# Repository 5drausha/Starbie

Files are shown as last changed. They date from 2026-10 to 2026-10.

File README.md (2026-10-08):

# Squarebie

This project is a modification of the Starbie starter project. Since I wanted to make something original, I decided to go down a slightly different path to Starbie. I wanted to turn this into more of a mini computer, desk assistant and macropad rather than a virtual pet.

Above is the picture of the 3d model (doesn't have the button caps in the model).

This is a picture of just the electronics.

This is the case.

And this is my PCB model.

My plan is to have this Squarbie be used as a sort of second mini device that pairs with my computer. I plan to have an app where you can do things such as set timers, reminders, make the 3 buttons on it customizable macropad keys, and display custom animations on it. But I'll have to leave that for later as I need the board in person (I don't know how to do it without it) to make the app. But for now, it functions as its own mini computer, with a stopwatch, a counter, and a reaction time game, which is still fully functional. Here is a picture of its simulated version:


This was a fun project and I learnt A LOT making this. I have never designed something in a CAD, so this was a great learning experience. Really looking forward to next week's project. :)

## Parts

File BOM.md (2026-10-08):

# Starbie – bill of materials

<!-- Generated by Half Life from project cmuuqodtk09mt01smeao56xzq. Edits here are overwritten on the next sync. -->
<!-- Generated: 2026-10-08T01:15:49.758Z -->

> [!NOTE]
> This parts list is mirrored from [Half Life](https://halflife.hackclub.com). Editing it here will not change the platform's copy, and the next sync overwrites this file.

| Week | Tier | Parts funding |
| --- | --- | --- |
| Week 1 | Tier 1 | $30.00 |

| Part | What it's for | Qty | Unit | Total | Vendor |
| --- | --- | --- | --- | --- | --- |
| [PCB board](https://cart.jlcpcb.com/quote?quoteTab=standardPcb) | Holds all the pieces and makes connections without wires. | 1 | $2.00 | $2.00 | [JLCPCB (JLCLONE)](https://cart.jlcpcb.com/quote?quoteTab=standardPcb) |
| [Seeed Studio XIAO ESP32 C3](https://www.aliexpress.com/item/1005007427033011.html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) | The main microcontroller of the whole project | 1 | $7.78 | $7.78 | [Aliexpress (SpotPear Electronics)](https://www.aliexpress.com/item/1005007427033011.html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) |
| [12mmx12mm tactile buttons](https://www.aliexpress.com/item/1005001629272642.html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) | The 3 buttons in the Squarebire I'm making (comes in packs of  10pcs) | 10 | $0.31 | $3.10 | [Aliexpress (HAPPYVIEW Electronics)](https://www.aliexpress.com/item/1005001629272642.html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) |
| [0.96 inch OLED I2C display](https://www.aliexpress.com/item/1005006901360788.html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) | The screen of the project, the output. | 1 | $2.69 | $2.69 | [Aliexpress (TENSTAR ROBOT Store)](https://www.aliexpress.com/item/1005006901360788.html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) |
| [Case top plate](https://jlc3dp.com/) | 3D printed case (top part) | 1 | $0.75 | $0.75 | [JLC3DP](https://jlc3dp.com/) |
| [Case Bottom Part](https://jlc3dp.com/) | What actually holds the components. The main Compartment | 1 | $1.59 | $1.59 | [JLC3DP](https://jlc3dp.com/) |
| **Parts subtotal** | — | — | — | **$17.91** | — |
| **Tax & shipping** | — | — | — | **$2.71** | — |
| **Total** | — | — | — | **$20.62** | — |

$9.38 left of the tier's funding.

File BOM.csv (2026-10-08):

Item | Quantity | Vendor | Unit Price (NZD) | Total Price (USD)
Display_128x64_096_I2C | 1 | Aliexpress | $4.79 | $2.69
12mmx12mm Tactile Switch | 10 | Aliexpress | $0.56 | $3.13
XIAO-ESP32 C6 DIP | 1 | Aliexpress | $13.90 | $7.78
PCB Board | 5 | JLCPCB | $0.71 | $2.00
Case (Bottom + Top) | 1 | JLC3DP | $4.18 | $2.34
Shipping + Tax | \ | \ | $4.84 | $2.71
Total | \ | \ | \ | $20.65

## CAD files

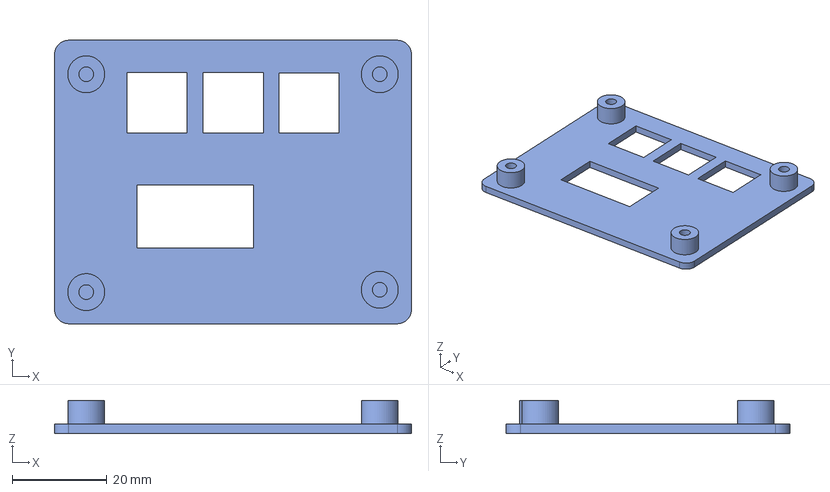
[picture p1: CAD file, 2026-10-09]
Top part of case (rounded).step
75.4 x 59.9 x 7.00 mm

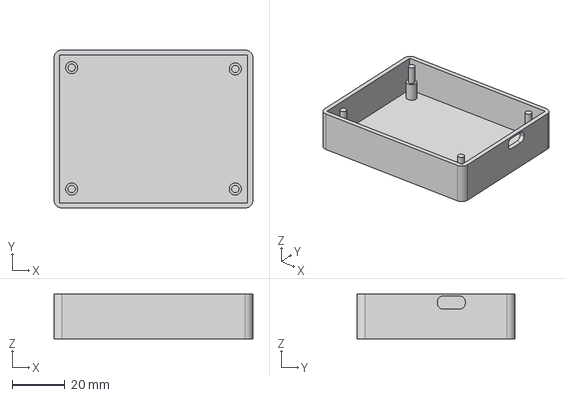
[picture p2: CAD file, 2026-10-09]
Bottom part of case (rounded).step
75.4 x 59.9 x 17.0 mm

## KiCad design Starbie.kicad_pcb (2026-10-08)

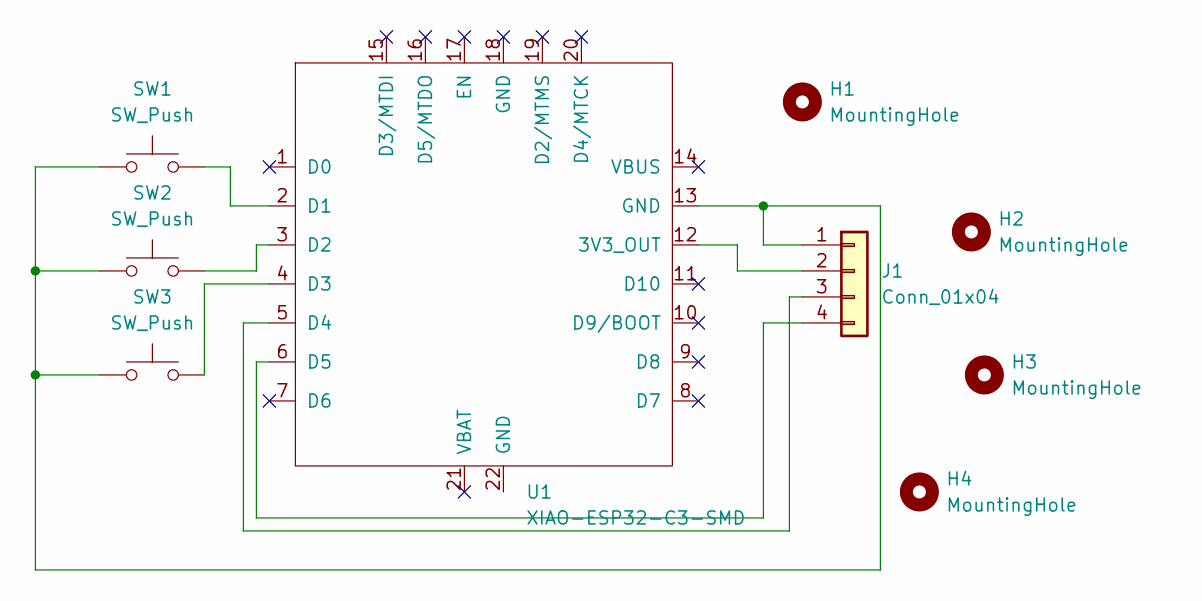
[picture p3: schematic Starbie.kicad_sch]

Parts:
H1, H2, H3, H4: MountingHole; MountingHole_3.2mm_M3
J1: Conn_01x04; Display_128x64_096_I2C
SW1, SW2, SW3: SW_Push; SW_PUSH-12mm
U1: XIAO-ESP32-C3-SMD; XIAO-ESP32-C6-DIP

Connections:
unnamed: J1.1, SW1.1, SW2.1, SW3.1, U1.13 (GND)
unnamed: J1.2, U1.12 (3V3_OUT)
unnamed: J1.3, U1.5 (D4)
unnamed: J1.4, U1.6 (D5)
unnamed: SW1.2, U1.2 (D1)
unnamed: SW2.2, U1.3 (D2)
unnamed: SW3.2, U1.4 (D3)

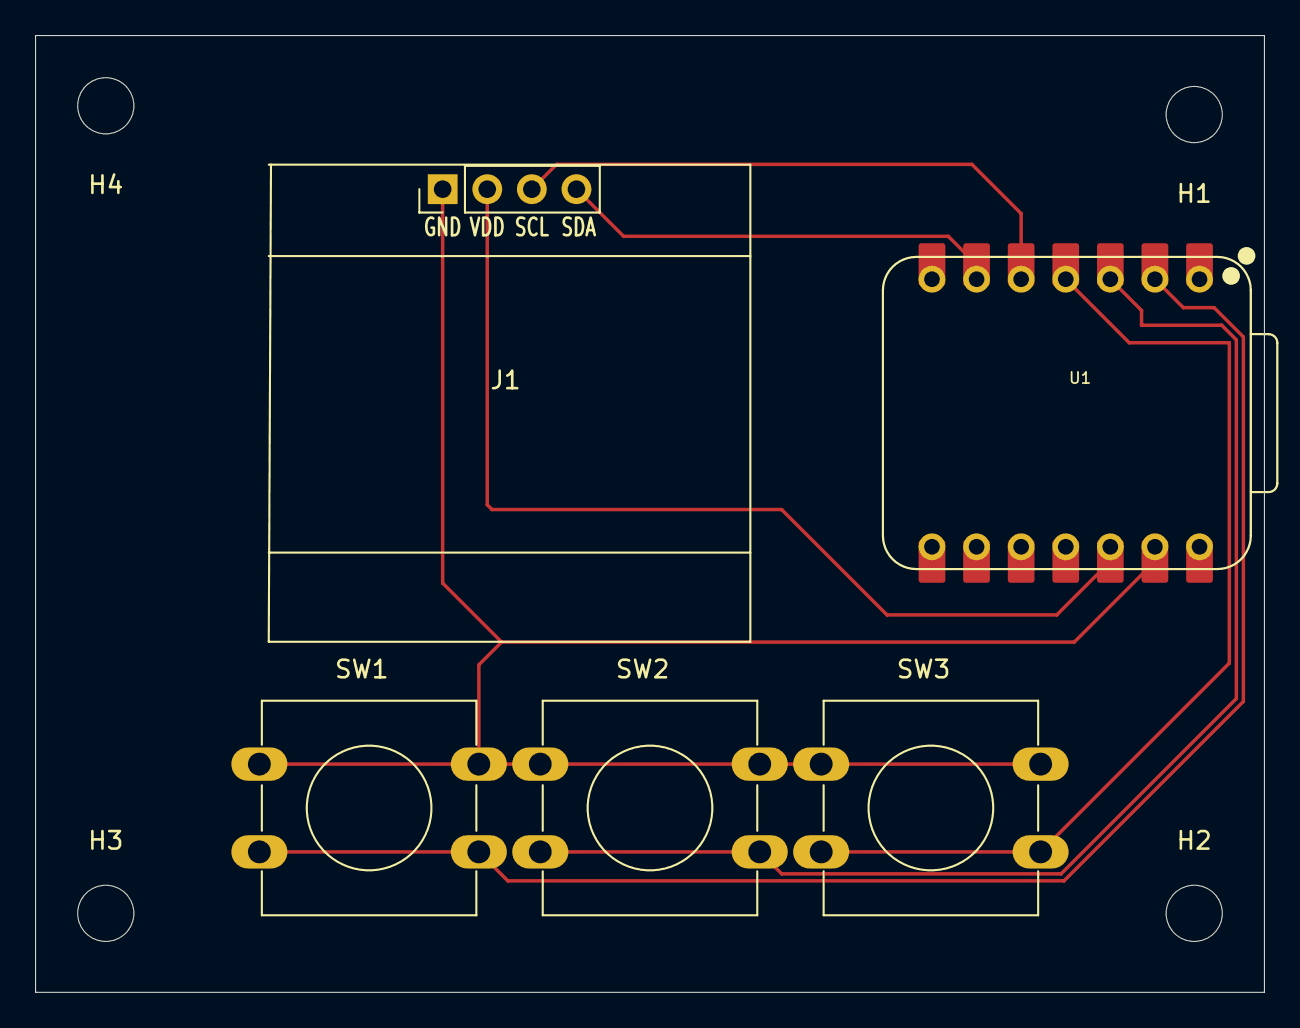
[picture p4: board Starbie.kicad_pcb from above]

Board: 2 copper layers, 70.0 x 54.5 mm, 9 parts (0 on the bottom side), 7 nets.

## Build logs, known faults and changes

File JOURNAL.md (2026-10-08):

# Starbie – devlog

<!-- Generated by Half Life from project cmuuqodtk09mt01smeao56xzq. Edits here are overwritten on the next sync. -->
<!-- Generated: 2026-10-08T00:15:37.416Z -->

> [!NOTE]
> This devlog is mirrored from [Half Life](https://halflife.hackclub.com). Editing it here will not change the platform's copy, and the next sync overwrites this file.

> A tiny motion-controlled digital pet, basically a desktop Tamagotchi. Totally not a Starboy.

| Week | Tier | Hours logged | Entries |
| --- | --- | --- | --- |
| Week 1 | Tier 1 | 17.5h | 4 |

## Contents

1. [2026-10-05 – October 5th: Learning Onshape and CAD modelling](#2026-10-05-october-5th-learning-onshape-and-cad-modelling)
2. [2026-10-05 – October 6th: Beginning the project, Making the PCB, Schematic, and BOM.](#2026-10-05-october-6th-beginning-the-project-making-the-pcb-)
3. [2026-10-07 – October 7th: Modelling the case in Onshape.](#2026-10-07-october-7th-modelling-the-case-in-onshape)
4. [2026-10-07 – October 8th: Finished the Case, Updated the BOM](#2026-10-07-october-8th-finished-the-case-updated-the-bom)

## Design

### 2026-10-05 – October 5th: Learning Onshape and CAD modelling

**4h**

October 5th: Learning Onshape and CAD modelling

This session was entirely focused on learning how CADs worked. I've never really used them so I wanted to get a bit of experience. I tried a lot of different CADs such as Shapr3D, Tinkercad, and Autodesk Fusion, which took up a lot of time, but what worked best was Onshape. I found it out through people guiding me through the Hack Club Slack forum, so thanks to that.
I did the Bakebuild Onshape tutorial provided by Hack Club. These are some of the Cookie cutters I made:
D cookie

They aren't the best, but they did help me understand how it worked. Then I spent some time playing around with Onshape, and after about an hour or so, I was able to make a sofa. I think it really helped me grasp the fundamentals and understand how the CAD worked.


I also watched a few tutorials, and I found this one very useful:


### 2026-10-05 – October 6th: Beginning the project, Making the PCB, Schematic, and BOM.

**7h**

October 6th: Beginning the project, Making the PCB, Schematic, and BOM.

So first, I started to brainstorm ideas because I didn't want it to be a boring copy of the starbie project, so I decided to make it more of like a handheld console kinda thing with 3 buttons, removing the sensors. This was my original rough plan of what it would look like.

So I started building it in Kicad. I also had to kind of learn how to use Kicad as it was my first time. I watched a few tutorials and using help from the starbie project guide I got to this:

Then I made the PCB, which was a little annoying to learn cuz the interface  wasn't very intuitive and i had trouble with part footprint libraries and stuff. But eventually I got to this.


Then I started to look for parts on Aliexpress, but then I realized how expensive the XIAO ESP32 C3 was, and it took up half of my budget. It was around $15-$17 dollars. With my other parts, it came to about $31 dollars before pcb manufacturing and 3d printing costs. This took up most of my time. After a really long time of searching, I still couldn't find anything, the closest being $27.50.


So after an unsuccessful search for parts, I finally came to the conclusion that I wouldn't be able to use the XIAO ESP32 C3 and that I'm going to have to use something else like the base model ESP32 C3 SuperMini, which is far cheaper.

I also got a quote for the cost to make the PCB which is $2, and shipping is $1.5.

I'm going to have to redo the schematics and PCB with a new microcontroller.

Edit: Never mind, I won't have to, I just realized this whooole thing is in USD and not NZD, giving me a total NZD budget of $53.50. That should just be enough for Everything. That brings the total parts cost to $20.36 USD, $16.86 for parts and $3.5 for the PCB with shipping Included. But I will have to buy a Soldering Iron and some solder.

### 2026-10-07 – October 7th: Modelling the case in Onshape.

**4h**

October 7th: Modelling the case in Onshape.

This was reaaally frustrating. Importing the pieces was pretty hard. I had to find 3d models for the buttons i was using. That took quite a while, but eventually I got to this:

After that I had to make the case. I tried a bunch of different designs. At first I tried to make screw holes, then i switched to pillars, then I had to reinforce the pillars to make sure they didn't break. Finally, this was the design i thought worked best:


The USB port was also a bigger challenge than you would expect. I had to figure out how to hide the components, then I messed around with the hole tool which didn't work, and I had to use the extrude tool. Then I realized that I had to make a bigger hole since the USB port didn't come all the way out, so the hole has to be quite big and ugly:

Now I have to make the top part of the case, which I have no clue how to do. There are a lot of different options, but all of them are pretty hard to do. Currently, my best contender is a sliding contraption with a screw, but that's pretty hard to do, so I'll have to leave that for another session. I made progress this session, just not as much as I expected to.

### 2026-10-07 – October 8th: Finished the Case, Updated the BOM

**2.5h**

October 8th: Finished the Case, Updated the BOM

I finally finished the case, making the front case plate, with an attachable mechanism. This took me quite a while to think of and design, but I ended up making it. I made the attachable thing and the hole for the screen and buttons. Its obviously not the best thing in the world, but I'm pretty happy with it. Oh and for the model below I couldn't find a model for the button caps so it look a little weird.

I also updated the BOM. I removed the Soldering Iron after advice from other people, and after including my 3d printed parts, the total cost is now down to $20.

I also made some temporary firmware for my Squarbie Macropad thing. Its kind of its own mini computer for now, but later on I'm gonna design an app on my computer than can let me control the macropad, display timers on it, set reminders, and control what the buttons do. I think this project was pretty cool, and I'm excited to hold the final product in my hands in a couple of weeks.

Now all I really have to do is update my Github Repo, verify my ID (there were problems with that so I reached out to support), and then I'm done! I can't really make the app for it yet until i get the parts, so for now it will just be a mini computer thing. Short but productive session today!

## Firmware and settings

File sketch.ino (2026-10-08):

#include <Wire.h>
#include <Adafruit_GFX.h>
#include <Adafruit_SSD1306.h>

#define SCREEN_WIDTH 128
#define SCREEN_HEIGHT 64
#define OLED_RESET    -1

#define OLED_SCL 6
#define OLED_SDA 7

#define BUTTON_1 3
#define BUTTON_2 4
#define BUTTON_3 5

Adafruit_SSD1306 display(SCREEN_WIDTH, SCREEN_HEIGHT, &Wire, OLED_RESET);

enum AppState { STATE_MENU, STATE_COUNTERS, STATE_STOPWATCH, STATE_REACTION };
AppState currentState = STATE_MENU;

enum IconType { ICON_UP, ICON_DOWN, ICON_SELECT, ICON_PLUS, ICON_PLAY, ICON_PAUSE, ICON_RESET, ICON_EXIT, ICON_READY, ICON_NONE };

int menuIndex = 0;

int count1 = 0;
int count2 = 0;

unsigned long swStartTime = 0;
unsigned long swElapsedTime = 0;
bool swRunning = false;

enum ReactionState { RX_IDLE, RX_WAITING, RX_GO, RX_RESULT, RX_EARLY };
ReactionState rxState = RX_IDLE;

unsigned long rxTargetTime = 0;
unsigned long rxStartTime = 0;
unsigned long rxScoreMs = 0;

bool lastBtn1 = HIGH;
bool lastBtn2 = HIGH;
bool lastBtn3 = HIGH;

void setup() {
  pinMode(BUTTON_1, INPUT_PULLUP);
  pinMode(BUTTON_2, INPUT_PULLUP);
  pinMode(BUTTON_3, INPUT_PULLUP);

  Wire.begin(OLED_SDA, OLED_SCL);

  if (!display.begin(SSD1306_SWITCHCAPVCC, 0x3C)) {
    if (!display.begin(SSD1306_SWITCHCAPVCC, 0x3D)) {
      for (;;);
    }
  }

  randomSeed(analogRead(0) + micros());

  display.setTextWrap(false);
  updateDisplay();
}

void loop() {
  bool btn1 = digitalRead(BUTTON_1);
  bool btn2 = digitalRead(BUTTON_2);
  bool btn3 = digitalRead(BUTTON_3);

  bool needRedraw = false;
  unsigned long now = millis();

  if (btn1 == LOW && lastBtn1 == HIGH) {
    if (currentState == STATE_MENU) {
      menuIndex = (menuIndex - 1 + 3) % 3;
      needRedraw = true;
    } else if (currentState == STATE_COUNTERS) {
      count1++;
      needRedraw = true;
    } else if (currentState == STATE_STOPWATCH) {
      if (swRunning) {
        swRunning = false;
        swElapsedTime = now - swStartTime;
      } else {
        swRunning = true;
        swStartTime = now - swElapsedTime;
      }
      needRedraw = true;
    } else if (currentState == STATE_REACTION) {
      if (rxState == RX_WAITING) {
        rxState = RX_EARLY;
        needRedraw = true;
      } else if (rxState == RX_GO) {
        rxScoreMs = now - rxStartTime;
        rxState = RX_RESULT;
        needRedraw = true;
      }
    }
  }

  if (btn2 == LOW && lastBtn2 == HIGH) {
    if (currentState == STATE_MENU) {
      menuIndex = (menuIndex + 1) % 3;
      needRedraw = true;
    } else if (currentState == STATE_COUNTERS) {
      count2++;
      needRedraw = true;
    } else if (currentState == STATE_STOPWATCH) {
      swRunning = false;
      swElapsedTime = 0;
      needRedraw = true;
    } else if (currentState == STATE_REACTION) {
      if (rxState == RX_IDLE || rxState == RX_RESULT || rxState == RX_EARLY) {
        rxState = RX_WAITING;
        rxTargetTime = now + random(2000, 5001);
        needRedraw = true;
      }
    }
  }

  if (btn3 == LOW && lastBtn3 == HIGH) {
    if (currentState == STATE_MENU) {
      if (menuIndex == 0) currentState = STATE_COUNTERS;
      else if (menuIndex == 1) currentState = STATE_STOPWATCH;
      else if (menuIndex == 2) {
        currentState = STATE_REACTION;
        rxState = RX_IDLE;
      }
    } else {
      currentState = STATE_MENU;
    }
    needRedraw = true;
  }

  lastBtn1 = btn1;
  lastBtn2 = btn2;
  lastBtn3 = btn3;

  if (currentState == STATE_REACTION && rxState == RX_WAITING) {
    if (now >= rxTargetTime) {
      rxState = RX_GO;
      rxStartTime = now;
      needRedraw = true;
    }
  }

  if (currentState == STATE_STOPWATCH && swRunning) {
    needRedraw = true;
  }

  if (needRedraw) {
    updateDisplay();
  }

  delay(10);
}

void drawIcon(int x, int y, IconType icon) {
  switch (icon) {
    case ICON_UP:
      display.fillTriangle(x + 3, y, x, y + 5, x + 6, y + 5, SSD1306_WHITE);
      break;
    case ICON_DOWN:
      display.fillTriangle(x, y, x + 6, y, x + 3, y + 5, SSD1306_WHITE);
      break;
    case ICON_SELECT:
      display.fillTriangle(x, y, x, y + 6, x + 5, y + 3, SSD1306_WHITE);
      break;
    case ICON_PLUS:
      display.drawFastHLine(x, y + 3, 7, SSD1306_WHITE);
      display.drawFastVLine(x + 3, y, 7, SSD1306_WHITE);
      break;
    case ICON_PLAY:
      display.fillTriangle(x + 1, y, x + 1, y + 6, x + 6, y + 3, SSD1306_WHITE);
      break;
    case ICON_PAUSE:
      display.fillRect(x + 1, y, 2, 6, SSD1306_WHITE);
      display.fillRect(x + 5, y, 2, 6, SSD1306_WHITE);
      break;
    case ICON_RESET:
      display.drawCircle(x + 3, y + 3, 3, SSD1306_WHITE);
      display.drawPixel(x + 3, y + 3, SSD1306_WHITE);
      break;
    case ICON_EXIT:
      display.fillTriangle(x, y + 3, x + 4, y, x + 4, y + 6, SSD1306_WHITE);
      display.drawFastHLine(x + 3, y + 3, 4, SSD1306_WHITE);
      break;
    case ICON_READY:
      display.drawRect(x, y + 1, 6, 5, SSD1306_WHITE);
      display.drawPixel(x + 3, y + 3, SSD1306_WHITE);
      break;
    case ICON_NONE:
      break;
  }
}

void drawBottomFooter(IconType icon1, IconType icon2, IconType icon3) {
  if (icon1 != ICON_NONE) drawIcon(18, 56, icon1);
  if (icon2 != ICON_NONE) drawIcon(60, 56, icon2);
  if (icon3 != ICON_NONE) drawIcon(102, 56, icon3);
}

void renderMenu() {
  display.setTextSize(1);
  display.setCursor(14, 8);
  if (menuIndex == 0) display.print("> "); else display.print("  ");
  display.print("1. Counters");

  display.setCursor(14, 22);
  if (menuIndex == 1) display.print("> "); else display.print("  ");
  display.print("2. Stopwatch");

  display.setCursor(14, 36);
  if (menuIndex == 2) display.print("> "); else display.print("  ");
  display.print("3. Reaction Test");

  drawBottomFooter(ICON_UP, ICON_DOWN, ICON_SELECT);
}

void renderCountersApp() {
  display.setTextSize(1);
  display.setCursor(32, 4);
  display.print("2x COUNTERS");

  display.setCursor(12, 26);
  display.print("C1: "); display.print(count1);

  display.setCursor(72, 26);
  display.print("C2: "); display.print(count2);

  drawBottomFooter(ICON_PLUS, ICON_PLUS, ICON_EXIT);
}

void renderStopwatchApp() {
  display.setTextSize(1);
  display.setCursor(38, 4);
  display.print("STOPWATCH");

  unsigned long totalMs = swRunning ? (millis() - swStartTime) : swElapsedTime;
  unsigned int mins = (totalMs / 60000) % 60;
  unsigned int secs = (totalMs / 1000) % 60;
  unsigned int hundredths = (totalMs / 10) % 100;

  display.setTextSize(2);
  display.setCursor(14, 24);

  if (mins < 10) display.print("0");
  display.print(mins);
  display.print(":");

  if (secs < 10) display.print("0");
  display.print(secs);
  display.print(".");

  if (hundredths < 10) display.print("0");
  display.print(hundredths);

  drawBottomFooter(swRunning ? ICON_PAUSE : ICON_PLAY, ICON_RESET, ICON_EXIT);
}

void renderReactionApp() {
  if (rxState == RX_IDLE) {
    display.setTextSize(1);
    display.setCursor(24, 4);
    display.print("REACTION TEST");

    display.setCursor(22, 26);
    display.print("Press ");
    drawIcon(58, 26, ICON_READY);
    display.setCursor(68, 26);
    display.print(" to Start");

    drawBottomFooter(ICON_NONE, ICON_READY, ICON_EXIT);
  } 
  else if (rxState == RX_WAITING) {
    display.setTextSize(2);
    display.setCursor(24, 24);
    display.print("WAIT...");
  } 
  else if (rxState == RX_GO) {
    display.fillRect(0, 0, 128, 64, SSD1306_WHITE);
    display.setTextColor(SSD1306_BLACK, SSD1306_WHITE);
    display.setTextSize(2);
    display.setCursor(28, 24);
    display.print("PRESS!");
  } 
  else if (rxState == RX_RESULT) {
    display.setTextSize(1);
    display.setCursor(28, 4);
    display.print("YOUR TIME:");

    display.setTextSize(2);
    display.setCursor(24, 24);
    display.print(rxScoreMs);
    display.print(" ms");

    drawBottomFooter(ICON_NONE, ICON_READY, ICON_EXIT);
  } 
  else if (rxState == RX_EARLY) {
    display.setTextSize(2);
    display.setCursor(4, 24);
    display.print("TOO EARLY!");

    drawBottomFooter(ICON_NONE, ICON_READY, ICON_EXIT);
  }
}

void updateDisplay() {
  display.clearDisplay();
  display.setTextColor(SSD1306_WHITE);

  if (currentState == STATE_MENU) {
    renderMenu();
  } else if (currentState == STATE_COUNTERS) {
    renderCountersApp();
  } else if (currentState == STATE_STOPWATCH) {
    renderStopwatchApp();
  } else if (currentState == STATE_REACTION) {
    renderReactionApp();
  }

  display.display();
}
